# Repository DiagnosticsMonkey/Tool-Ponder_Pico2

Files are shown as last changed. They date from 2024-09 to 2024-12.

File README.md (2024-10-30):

# ReadMe

Ponder - Pico 2 is a varient of Ponder, designed to act as 6, electrically isolated, UART to USB bridges using the Pico 2.
Connect the board to your PC, and be served 6, driverless, COM-ports or ttyACM devices.

## Documentation

Documentation is captured in Markdown and is available in `/docs`, rendered [using docsify here](https://diagnosticsmonkey.github.io/Tool-Ponder_Pico2/#/).

## Design files

All of the design files are included in this repository.

### Hardware

Hardware design files are in [`/hardware`](https://github.com/DiagnosticsMonkey/Tool-Ponder_Pico2/tree/develop/hardware).

Generated outputs such as [Schematic](https://github.com/DiagnosticsMonkey/Tool-Ponder/blob/develop/hardware/outputs/Ponder-Pico2.pdf), [BoM](https://diagnosticsmonkey.github.io/Tool-Ponder_Pico2/#/design?id=bill-of-materials), and [Gerbers](https://github.com/DiagnosticsMonkey/Tool-Ponder_Pico2/tree/develop/hardware/outputs/fab) are all included.

### Software

Nominal software is available TBD.

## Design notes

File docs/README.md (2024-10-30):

# Ponder - Pico 2

> [!WARNING]This documentation is not yet complete

This board is primarily designed to act as a 6-way isolated USB-UART bridge using the Pico 2. This can be used to interface to multiple devices-under-test simultaneously.

Unlike FTDI devices, no additional drivers are required to be installed in order for the device to function as a UART to USB bridge; Support is baked in to modern operating system kernels using USB CDC ACM.

In short, it is a quick and convenient way to debug devices via UART. No need for multiple cables and isolators.

> [!NOTE]
> This board is a variant of [Ponder](https://diagnosticsmonkey.github.io/Tool-Ponder/#/)  
> It exists due to a pro-tracted lack of consumer supply for the RP2350B, yet abundant supply of Pico 2's. I want to get software sorted.

---

## Why Isolated?

There are a few reasons why it can be a good idea to electrically isolate your device under test from your test system, including:

1. Ground Loops -> Devices connected via UART may have different ground potentials. Without isolation, this could cause ground loops, which can lead to noise, signal integrity issues, or in severe cases, damage.
1. Damage to Equipment -> An isolated adapter prevents high-voltage from being passed to the USB port of the host computer.
   1. e.g. If you have a battery powered device and you're low-side switching, the product will float to the pack voltage when 'off'. This could damage any connected equipment due to the potential difference.
1. Noise Reduction -> Isolation reduces electrical noise, improving signal integrity and communication reliability.
1. Safety -> Protects the user, and equipment, when working with high-voltage or hazardous devices.
   1. N.B. electrical isolation should be verified by an electrical safety team before being used as a safety device.
1. Improved Debugging -> Issues with one device, shouldn't be able to impinge on the UART comms of another under test.

### Why not isolate the USB

By isolating the individual UARTs you're able to connect to different voltage domains simultaneously. This means that Ponder can be installed as part of a debug or test ecosystem for a full product comprising of multiple referencing domains.  
The downside is that even if you're communicating with several UARTs on the same board, each isolator requires its own voltage feed. 

---

## Naming

Ponder is named after [Ponder Stibbons](https://wiki.lspace.org/Ponder_Stibbons), Head of Inadvisably Applied Magic, and Reader in Invisible Writings.

Ponder Stibbons is from the [Discworld universe](https://wiki.lspace.org/Discworld_(world)), brought in to existence by [Sir Terry Pratchett](https://wiki.lspace.org/Biography).

---

## Attribution

- Pico footprint from ncarandini -> https://github.com/ncarandini/KiCad-RP-Pico
  - Modified to add Pico 2 TPs and adjust USB mount holes
- Raspberry Pi - Pico 2 model used is originally by DrakerDG -> https://www.tinkercad.com/things/4xIXctwrZsr-raspberry-pi-pico-2
  - Modified to add TPs https://www.tinkercad.com/things/fXc3pdA6Lbr-raspberry-pi-pico-2-w-tps-rough
  - Converted from `OBJ` to `WRL` using -> https://imagetostl.com/convert/file/obj/to/wrl

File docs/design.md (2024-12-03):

# Design

Design files are all available in `/hardware` of the Ponder_Pico2 repository.

## Appearance

The board is _reasonably_ self-explanatory for most _intended_ users and is presented as follows:

<!-- tabs:start -->

#### **Render**

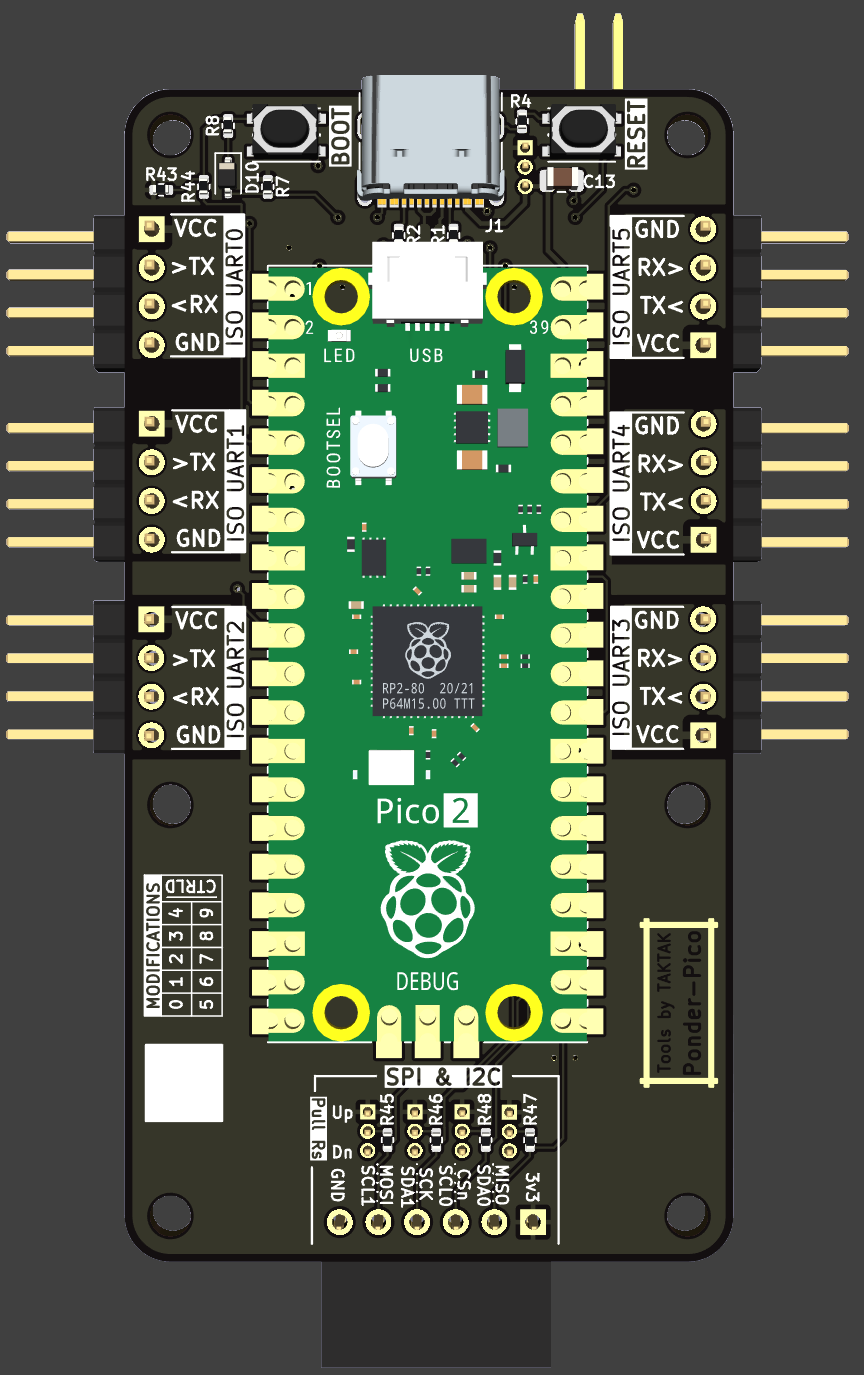
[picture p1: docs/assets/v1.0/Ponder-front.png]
Front of board :size=300
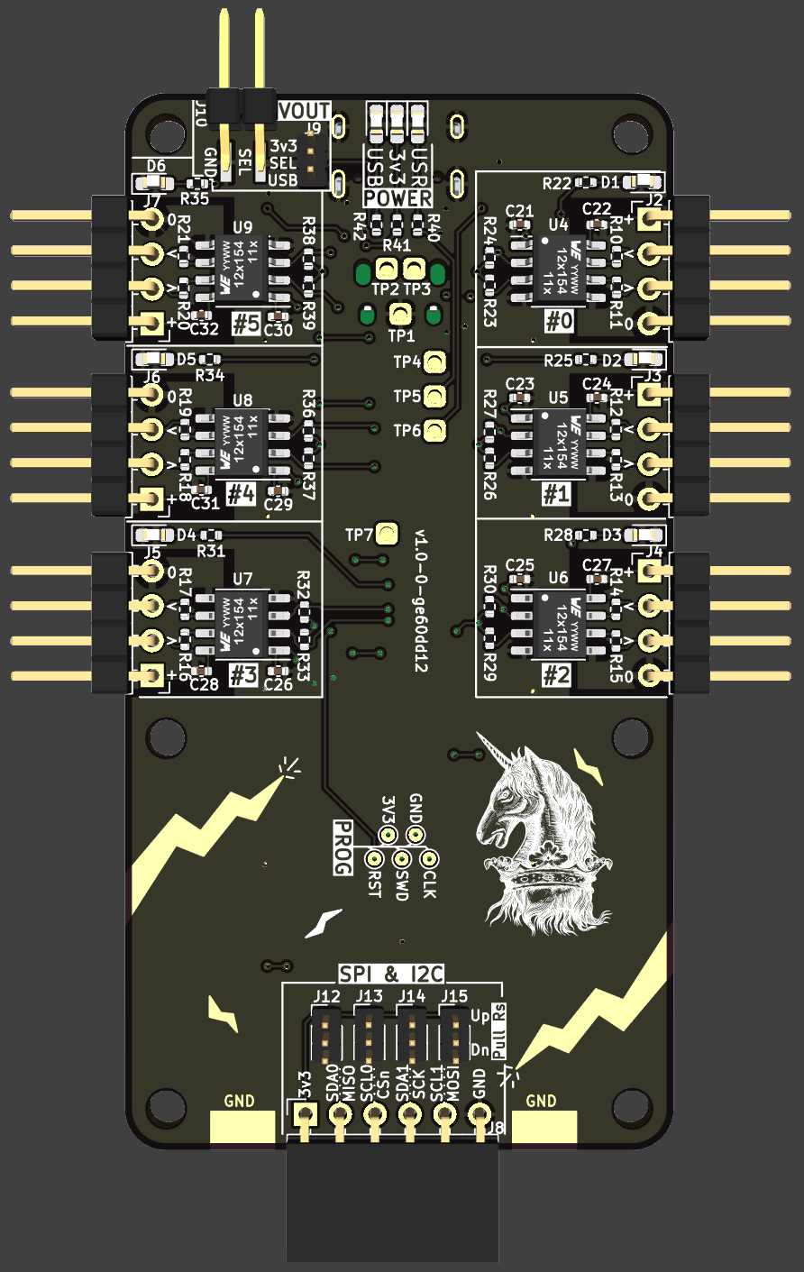
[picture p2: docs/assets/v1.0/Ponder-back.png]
Back of board :size=310
 

#### **Photo**

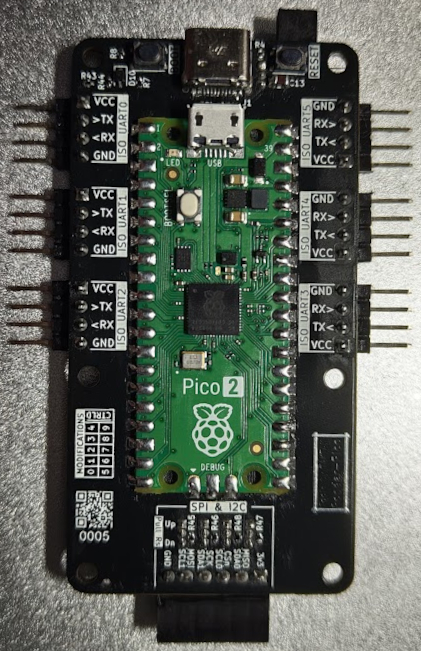
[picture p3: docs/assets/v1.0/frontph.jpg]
Front of board :size=300
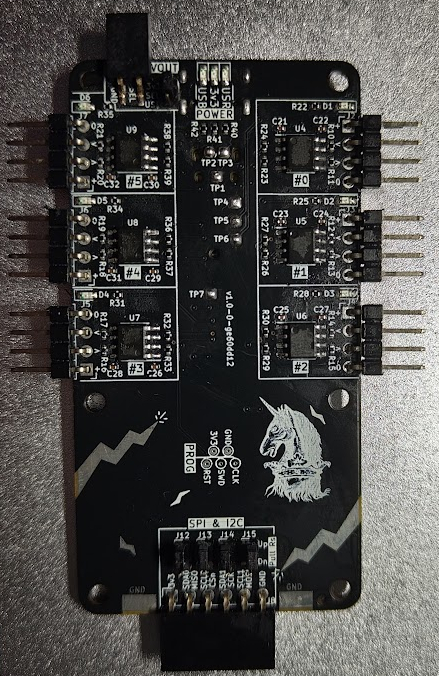
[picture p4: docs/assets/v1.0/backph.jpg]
Back of board :size=310
 

<!-- tabs:end -->

See [here for more detail of features and usage](/features)

---

## Bill of Materials

The below is an embedded copy of the interactive bill-of-materials, available in `/hardware/outputs/bom`.

[ibom](./assets/v1.0/ibom.html ':include :type=iframe width=100% height=800px')

---

## Schematic

Whilst the majority of the expanded headers are self explanatory, the following is embedded to provide a fuller picture of the board.

Available in `/hardware/outputs`.

```pdf
./assets/v1.0/Ponder-Pico2.pdf
```

---

## Miscellaneous

The following lists any miscellany.

### Board Revision

The board includes a version and revision marker which traces back to the applicable Git commit from which the bareboard was generated.

Revision

### Mod Strikes

On the rear of the board, there is a 'MODIFICATIONS' box for tracking board modifications via modification sheets, each assigned a number.
When a board is updated to a particular modification level, mark the corresponding box.

Mod strikes

Alternatively, if a board is used in a bespoke way, check the '/CTRLD' box to indicate it is not at a known, or controlled, build level.

>[!TIP]
>The `/CTRLD` box can be useful if you have multiple boards which you're tracking the status of, but you're experimenting heavily with one and are never intending on returning it to a defined build standard.

### Serialisation

Serialisation is provided next to the Mod Strike box in the form `ZZZZ`.

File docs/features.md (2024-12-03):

# Features

This page details the feature-set and pin-mapping at a high-level.

## Pinout

?>The following has been reproduced for ease of access, the schematic is the source of truth.

| Function | Ponder Pico2 | Ponder |
|:---:|:---:|:---:|
| UART0 TX | GPIO0 | GPIO0 |
| UART0 RX | GPIO1 | GPIO1 |
| UART0 LED | GPIO2 | GPIO2 |
| USR SW | GPIO3 | GPIO3 |
| UART1 TX | GPIO4 | GPIO20 |
| UART1 RX | GPIO5 | GPIO21 |
| UART1 LED | GPIO6 | GPIO8 |
| UART2 LED | GPIO7 | GPIO19 |
| UART2 TX | GPIO8 | GPIO22 |
| UART2 RX | GPIO9 | GPIO23 |
| UART3 LED | GPIO11 | GPIO30 |
| UART3 TX | GPIO12 | GPIO29 |
| UART3 RX | GPIO13 | GPIO28 |
| SPI**0** MISO/I2C0 SDA | GPIO16 | N/A |
| SPI**0** CSn/I2C0 SCL  | GPIO17 | N/A |
| SPI**0** SCK/I2C1 SDA  | GPIO18 | N/A |
| SPI**0** MOSI/I2C1 SCL | GPIO19 | N/A |
| UART4 RX | GPIO20 | GPIO32 |
| UART4 TX | GPIO21 | GPIO33 |
| UART4 LED | GPIO22 | GPIO34 |
| RP_PWR_LED | GPIO25 | GPIO4 |
| UART5 RX | GPIO26 | GPIO46 |
| UART5 TX | GPIO27 | GPIO47 |
| UART5 LED | GPIO28 | GPIO45 |

<details>
  <summary>For completeness -> SPI/I2C mapping for Ponder (Click to Expand)</summary>
Ponder Pico2 uses SPI0, Ponder uses SPI1.

| Function | Ponder Pico2 | Ponder |
|:---:|:---:|:---:|
| SPI**1** MISO/I2C0 SDA | N/A | GPIO24 |
| SPI**1** CSn/I2C0 SCL  | N/A | GPIO25 |
| SPI**1** SCK/I2C1 SDA  | N/A | GPIO26 |
| SPI**1** MOSI/I2C1 SCL | N/A | GPIO27 |

</details>

---

## Interfaces

The following sections will cover detail of various interfaces across the board.

>[!TIP]
>I _try_ to maintain the logic of not having `hot` supply pins as far as practicable.  
>This means that where possible, anything intended to provide a supply voltage will be in the form of a socket. Conversely, anything to be supplied a voltage will be presented as a header.  
>N.B. J10 is shown in renders as a header - It is a socket in the BoM. Its selection jumper, J9, is a 1.27 pitch for convenience.

---
### LEDS

There are three LEDs on the board which aren't for use with the ISO UARTS, these are:

1. USR - This is a user controllable LED, nominally used to indicate when the MCU has booted into user code
1. USB - This LED is tied to VBUS on the USB connector to indicate presence of power.
1. 3v3 - This is tied to the 3v3 line from the Pico to indicate that the LDO is functional.

### Buttons

#### BOOT

The BOOT button is used to put the MCU into USB bootloader mode in order to load *.UF2 files. Simply hold the button whilst powering on the board, then the board will present as a mass-storage device.

>[!TIP]
>Once booted, the button can act as a user input connected to `GPIO3`.

#### RESET

The reset button resets the device

### USB (J1)

The USB-C connector provides power to the board and is the primary mechanism for programming the board.  
During the boards intended use-case, the USB connector is also used for the data handling for the CDC ACM endpoints (i.e. your PC providing multiple COM ports for accessing each of the UARTs on-board).

---

### Isolated UARTs (J2, J3, J4, J5, J6, J7)

The isolated UARTs are provided by six 4 pin, 2.54 pitch, headers around the edge. The isolators connected to these headers `must` be fed with a voltage and ground reference by **each** device under test, otherwise the UART comms will not be passed to the MCU.

- Supply voltage on VCC for `UART`[`0` .. `5`] is 2.375 .. 5.5V  
   - The isolators are also providing level translation and will support logic from 2v0 to 5v5.

>[!NOTE]
>If you require 1v8 logic -> A drop-in replacement isolator is the [MAX12931](https://www.analog.com/media/en/technical-documentation/data-sheets/max12930-max12931.pdf).  
>This part is significantly higher cost, hence not the default.

---

### I2C / SPI / Breakout (J8, TPs)

The board includes some additional connection options for users to experiment with.

#### J8

J8 _nominally_ provides access to either `SPI0` _or_ `I2C0` & `IC21`. Additionally, the header provides 3v3 supply and GND connections.

J12 .. J15 provides optional pull-up / pull-down configuration for each pin by jumpering the desired end to the centre pin.

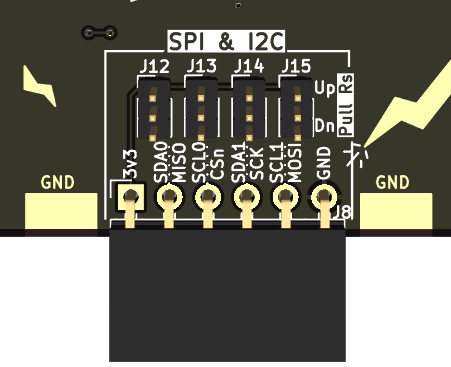
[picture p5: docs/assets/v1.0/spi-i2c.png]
SPI I2C :size=200


>[!TIP]
>These pins could be used for GPIO, for example for triggering wider aspects of a test system.

#### Programming

Test points are provided as an alternative to USB loading.

1. Programming test points are grouped near the MCU.
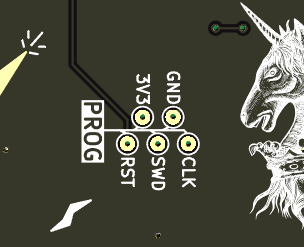
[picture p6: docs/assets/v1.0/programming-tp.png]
Prog :size=150
   1. 

### VOut (J10)

J10 is provided as a convenient power access for lower power devices or for monitoring supply voltages.  
The voltage on J10 can be selected, using J9. The options are 3v3 or USB.

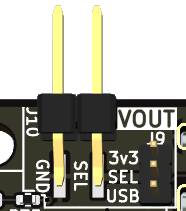
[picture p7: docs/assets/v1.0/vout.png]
VOUT


>[!WARNING]
>J10 _could_ be used to power the board, up-to 20V, when jumpered to USB, or a direct 3v3, bypassing the LDO (U1), if required.  
>If powering via the USB jumper option, note that USB LED, D9, is tied to this line and has 1kR in series.

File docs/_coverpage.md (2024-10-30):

:size=50%

#  Ponder <small>Pico 2 - 1.0</small>

>  Isolated Hexa UART-USB adapter from Diagnostics

- :see_no_evil:
- :hear_no_evil:
- :speak_no_evil:

[Purchase](/purchase)
[Getting Started](/README)

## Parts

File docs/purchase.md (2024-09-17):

# Purchase

To purchase Ponder for yourself, please contact me on `contact (at) taktak.co.uk` for details.

I'm currently working out where to make Ponder available, likely Tindie.

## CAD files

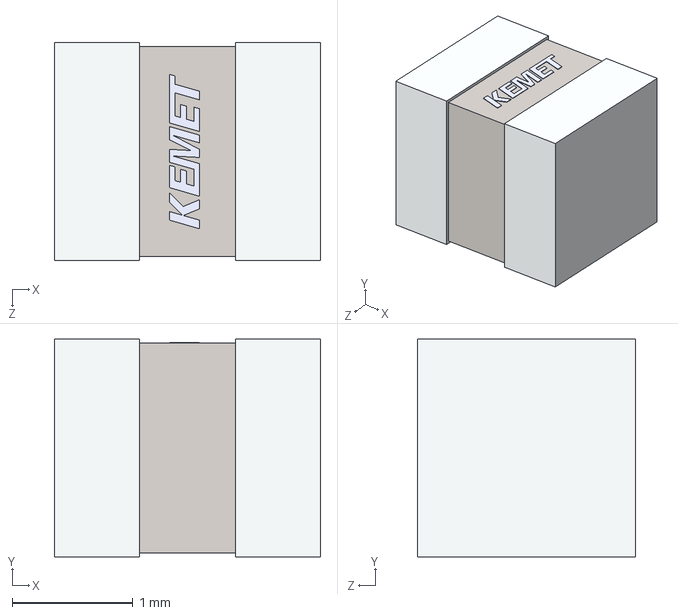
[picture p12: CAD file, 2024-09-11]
hardware/Parts/L0806.stp
2.20 x 1.80 x 1.80 mm

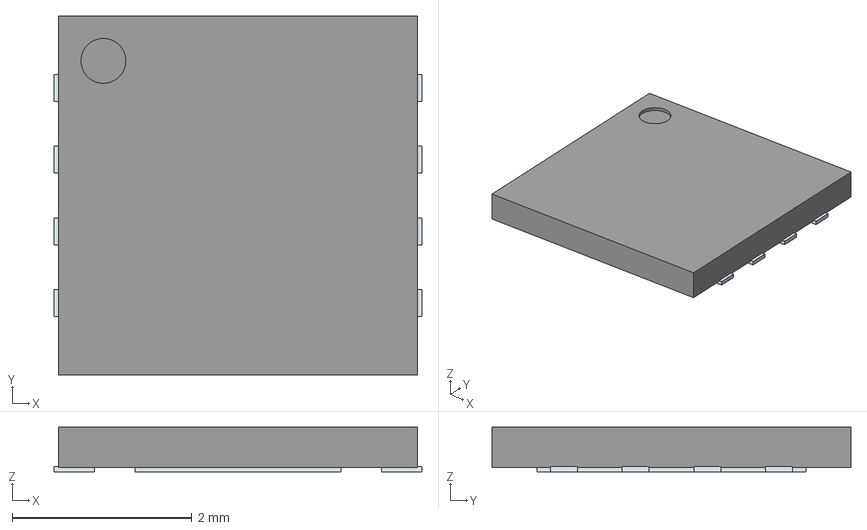
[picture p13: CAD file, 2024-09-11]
hardware/Parts/W25Q64JVXGIQ_TR.stp
4.10 x 4.00 x 0.5 mm
ThermalPin
PinsArrayLR

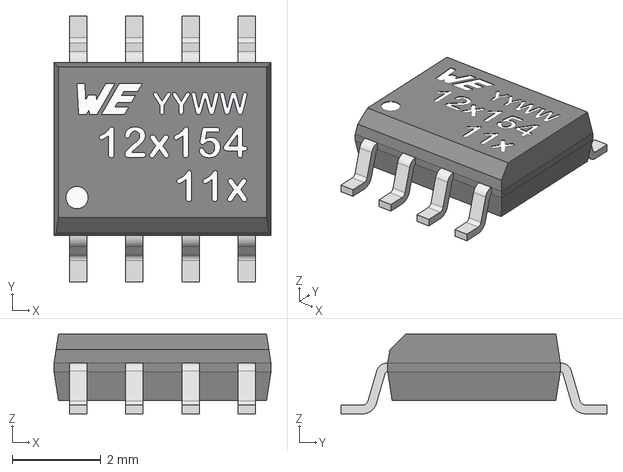
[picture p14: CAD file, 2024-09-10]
hardware/Parts/STP_CDIS_18012x15411x (rev1).stp
4.90 x 6.00 x 1.80 mm
Pins

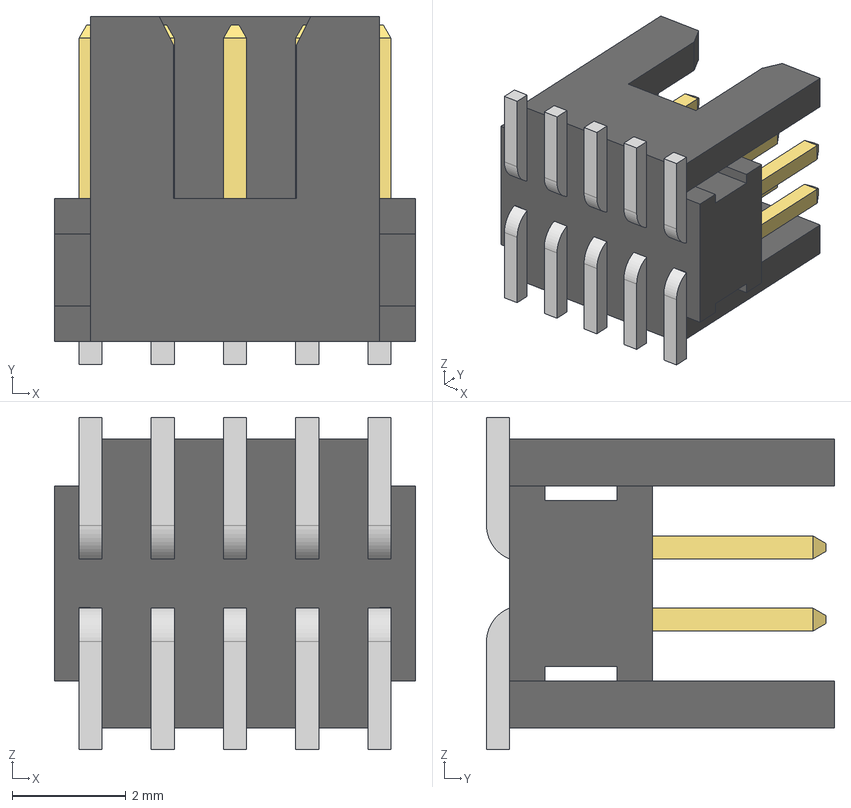
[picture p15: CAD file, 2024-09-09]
hardware/Parts/FTSH-105-01-L-DV-K.stp
6.35 x 6.12 x 5.84 mm
FTSH-105-01-L-DV-K_body
FTSH-105-01-L-DV-K_pins1
FTSH-105-01-L-DV-K_pins2

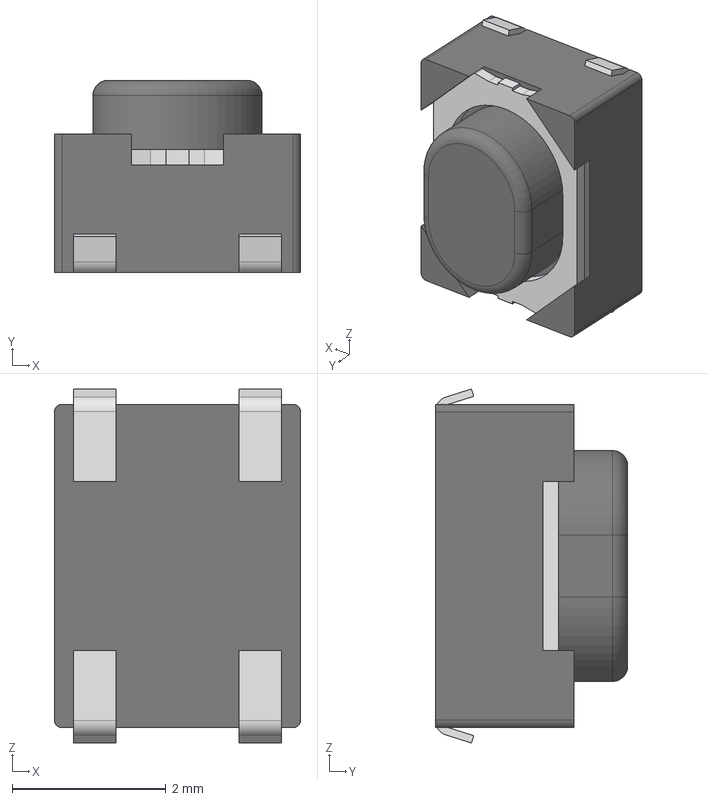
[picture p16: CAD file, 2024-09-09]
hardware/Parts/STP_4341x30258x6 (rev1).stp
3.20 x 2.50 x 4.60 mm
Frame
Cover
Stem
Terminal x 4

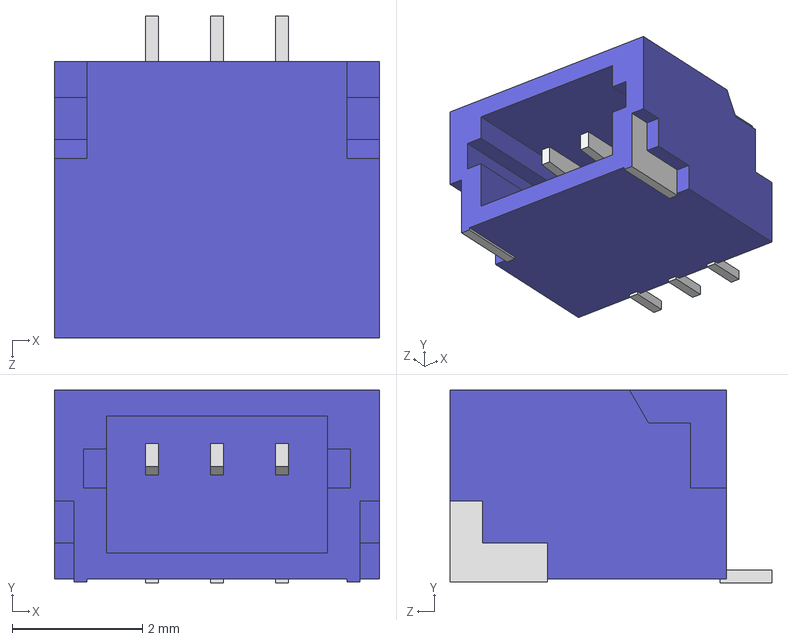
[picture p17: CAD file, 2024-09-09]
hardware/Parts/SM03B-SRSS-TB.step
5.00 x 2.96 x 4.95 mm

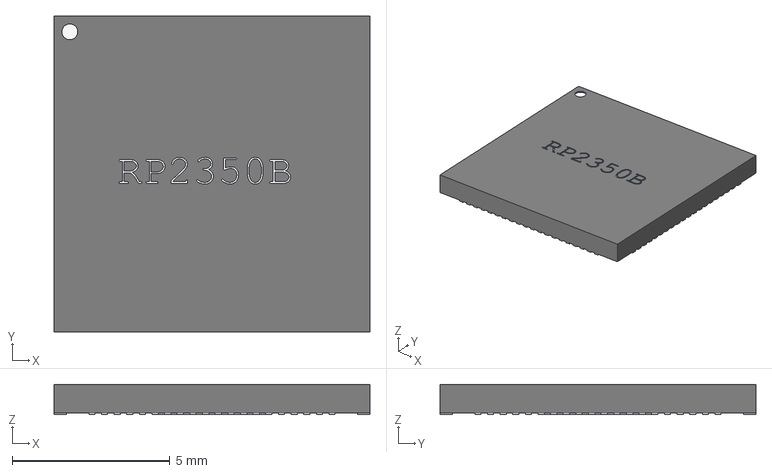
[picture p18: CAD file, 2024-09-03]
hardware/Parts/RP2350_QFN80.step
10.0 x 10.0 x 0.95 mm

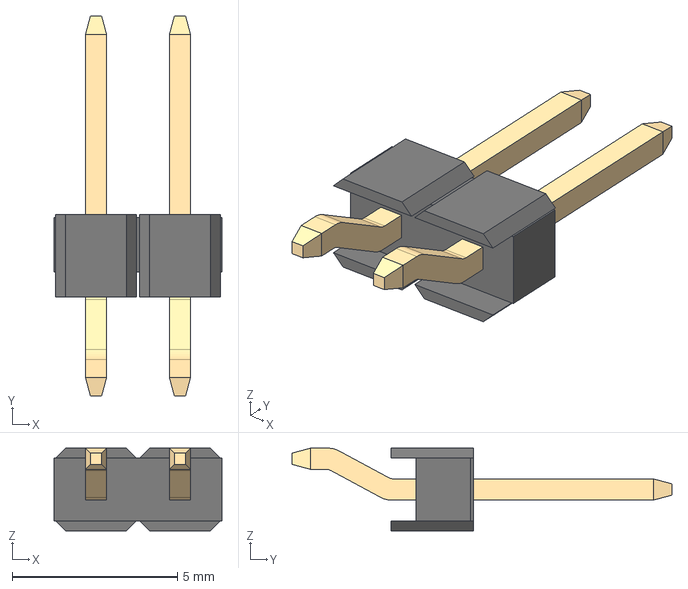
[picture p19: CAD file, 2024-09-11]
hardware/Parts/M20-8890245.stp
5.08 x 11.5 x 2.50 mm
M20-88902_MOULD
M20-889_CONTACT x 2

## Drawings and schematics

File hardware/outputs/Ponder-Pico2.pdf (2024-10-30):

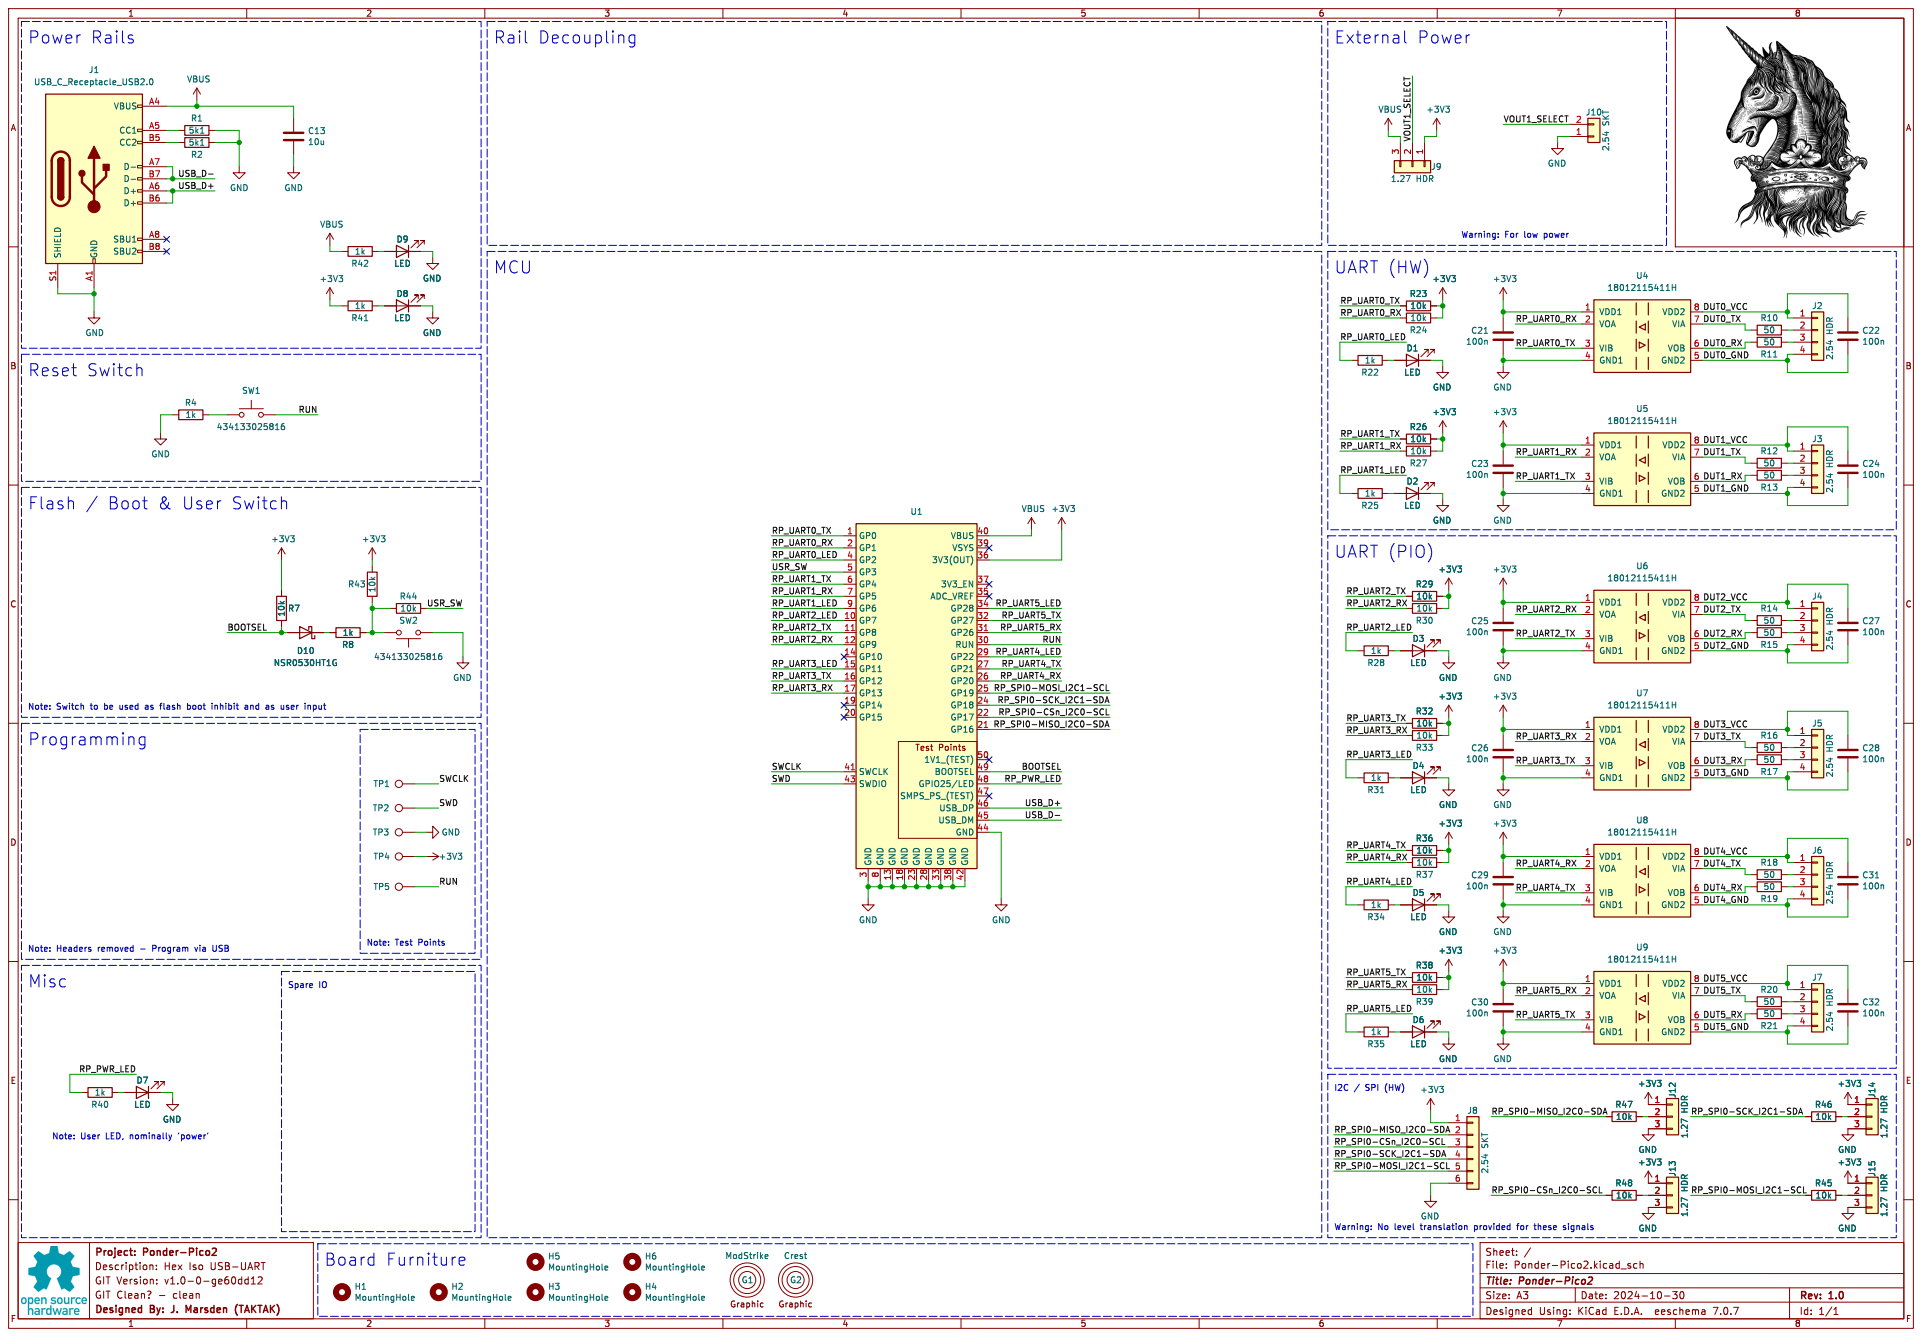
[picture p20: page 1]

BOOTSEL RP_SPI0-MISO_I2C0-SDA RP_SPI0-SCK_I2C1-SDA RUN

Flash / Boot & User Switch

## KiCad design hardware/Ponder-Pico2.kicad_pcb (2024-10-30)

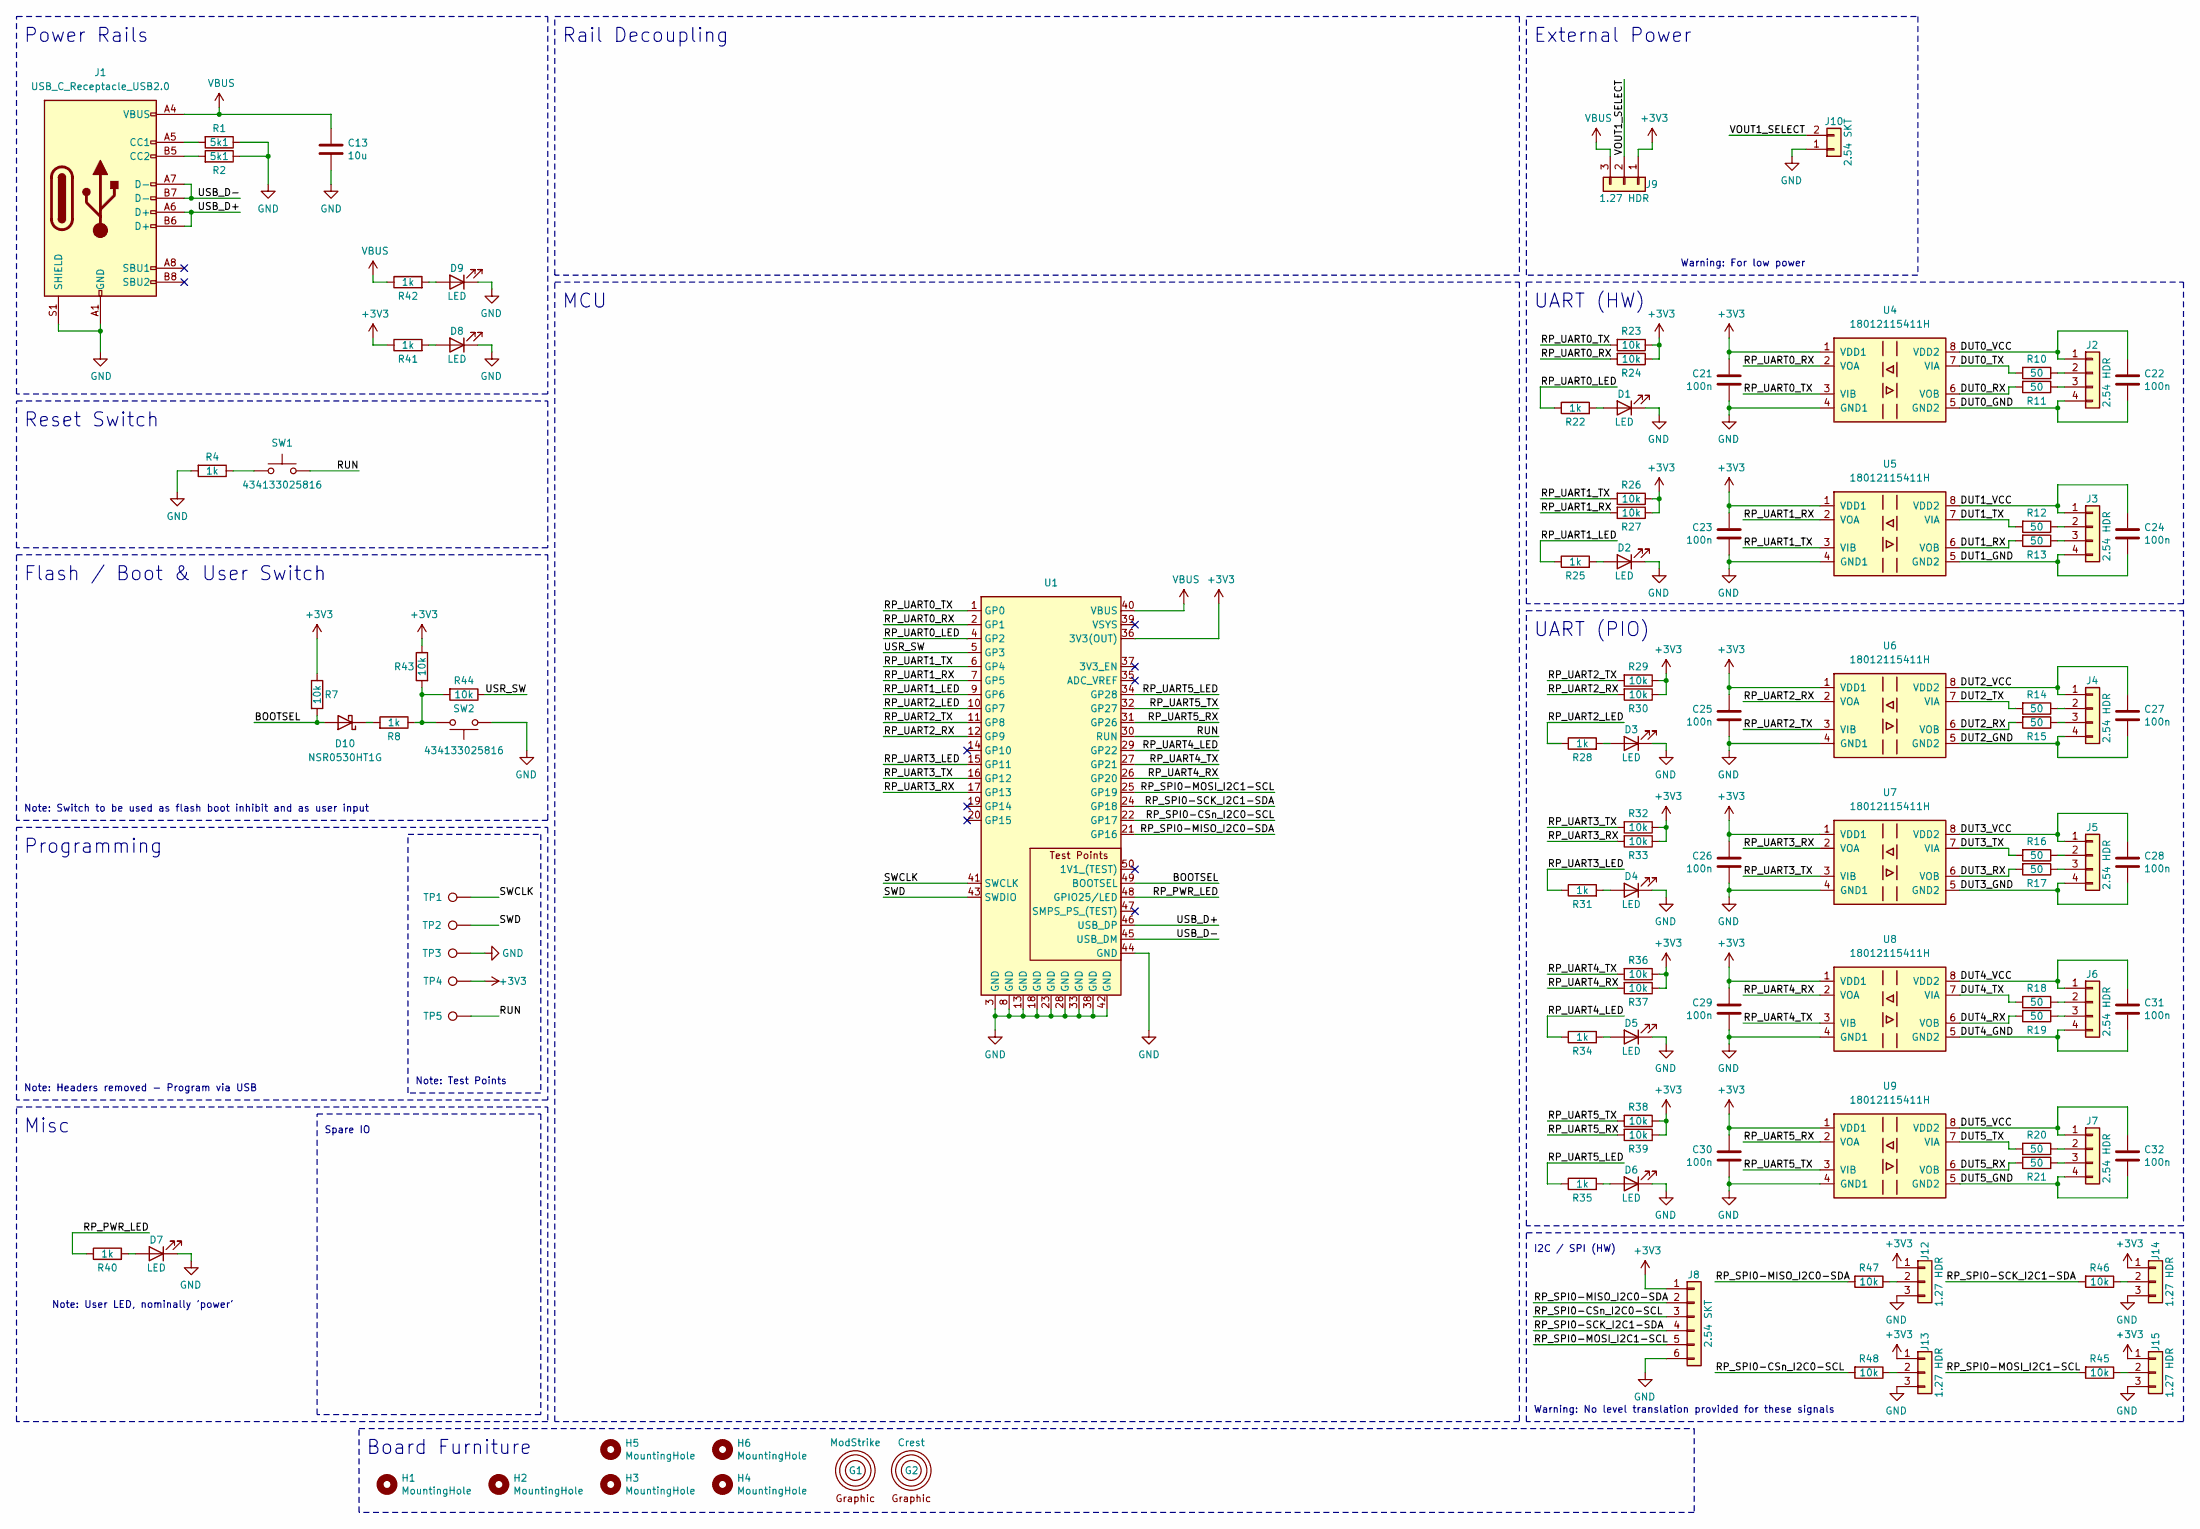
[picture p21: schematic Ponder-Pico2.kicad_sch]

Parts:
C13: 10u; C_0805_2012Metric
C21, C22, C23, C24, C25, C26, C27, C28, C29, C30, C31, C32: 100n; C_0402_1005Metric
D1, D2, D3, D4, D5, D6, D7, D8, D9: LED; LED_0603_1608Metric_Pad1.05x0.95mm_HandSolder
D10: NSR0530HT1G; D_SOD-323
G1: ModStrike
G2: Crest; Crest-10mm
H1, H2, H3, H4, H5, H6: MountingHole; MountingHole_2.7mm_M2.5
J1: USB_C_Receptacle_USB2.0; USB_C_Receptacle_GCT_USB4105-xx-A_16P_TopMnt_Horizontal
J2, J3, J4, J5, J6, J7: 2.54 HDR; PinHeader_1x04_P2.54mm_Horizontal
J8: 2.54 SKT; PinSocket_1x06_P2.54mm_Horizontal
J9, J12, J13, J14, J15: 1.27 HDR; PinHeader_1x03_P1.27mm_Vertical
J10: 2.54 SKT; M208890245
R1, R2: 5k1; R_0402_1005Metric
R4, R8, R22, R25, R28, R31, R34, R35, R40, R41, R42: 1k; R_0402_1005Metric
R7, R23, R24, R26, R27, R29, R30, R32, R33, R36, R37, R38, R39, R43, R44, R45, R46, R47, R48: 10k; R_0402_1005Metric
R10, R11, R12, R13, R14, R15, R16, R17, R18, R19, R20, R21: 50; R_0402_1005Metric
SW1, SW2: 434133025816; SW_Push_1P1T_NO_Vertical_Wuerth_434133025816
TP1, TP2, TP3, TP4, TP5: TestPoint; TestPoint_Pad_D1.0mm
U1: RaspberryPi-Pico-SMD-TP
U4, U5, U6, U7, U8, U9: 18012115411H; SOIC-8_3.9x4.9mm_P1.27mm

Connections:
+3V3: C21.1, C23.1, C25.1, C26.1, C29.1, C30.1, J8.1, J9.1, J12.1, J13.1, J14.1, J15.1, R7.1, R23.1, R24.1, R26.1, R27.1, R29.1, R30.1, R32.1, R33.1, R36.1, R37.1, R38.1, R39.1, R41.1, R43.1, TP4.1, U1.36 (3V3(OUT)), U4.1 (VDD1), U5.1 (VDD1), U6.1 (VDD1), U7.1 (VDD1), U8.1 (VDD1), U9.1 (VDD1)
/BOOTSEL: D10.2 (A), R7.2, U1.49 (BOOTSEL)
/DUT0_GND: C22.2, J2.4, U4.5 (GND2)
/DUT0_RX: R11.2, U4.6 (VOB)
/DUT0_TX: R10.2, U4.7 (VIA)
/DUT0_VCC: C22.1, J2.1, U4.8 (VDD2)
/DUT1_GND: C24.2, J3.4, U5.5 (GND2)
/DUT1_RX: R13.2, U5.6 (VOB)
/DUT1_TX: R12.2, U5.7 (VIA)
/DUT1_VCC: C24.1, J3.1, U5.8 (VDD2)
/DUT2_GND: C27.2, J4.4, U6.5 (GND2)
/DUT2_RX: R15.2, U6.6 (VOB)
/DUT2_TX: R14.2, U6.7 (VIA)
/DUT2_VCC: C27.1, J4.1, U6.8 (VDD2)
/DUT3_GND: C28.2, J5.4, U7.5 (GND2)
/DUT3_RX: R17.2, U7.6 (VOB)
/DUT3_TX: R16.2, U7.7 (VIA)
/DUT3_VCC: C28.1, J5.1, U7.8 (VDD2)
/DUT4_GND: C31.2, J6.4, U8.5 (GND2)
/DUT4_RX: R19.2, U8.6 (VOB)
/DUT4_TX: R18.2, U8.7 (VIA)
/DUT4_VCC: C31.1, J6.1, U8.8 (VDD2)
/DUT5_GND: C32.2, J7.4, U9.5 (GND2)
/DUT5_RX: R21.2, U9.6 (VOB)
/DUT5_TX: R20.2, U9.7 (VIA)
/DUT5_VCC: C32.1, J7.1, U9.8 (VDD2)
/RP_PWR_LED: R40.1, U1.48 (GPIO25/LED)
/RP_SPI0-CSn_I2C0-SCL: J8.3, R48.2, U1.22 (GP17)
/RP_SPI0-MISO_I2C0-SDA: J8.2, R47.2, U1.21 (GP16)
/RP_SPI0-MOSI_I2C1-SCL: J8.5, R45.2, U1.25 (GP19)
/RP_SPI0-SCK_I2C1-SDA: J8.4, R46.2, U1.24 (GP18)
/RP_UART0_LED: R22.1, U1.4 (GP2)
/RP_UART0_RX: R24.2, U1.2 (GP1), U4.2 (VOA)
/RP_UART0_TX: R23.2, U1.1 (GP0), U4.3 (VIB)
/RP_UART1_LED: R25.1, U1.9 (GP6); also elsewhere on the board
/RP_UART1_RX: R27.2, U1.7 (GP5), U5.2 (VOA)
/RP_UART1_TX: R26.2, U1.6 (GP4), U5.3 (VIB)
/RP_UART2_LED: R28.1, U1.10 (GP7)
/RP_UART2_RX: R30.2, U1.12 (GP9), U6.2 (VOA)
/RP_UART2_TX: R29.2, U1.11 (GP8), U6.3 (VIB)
/RP_UART3_LED: R31.1, U1.15 (GP11)
/RP_UART3_RX: R33.2, U1.17 (GP13), U7.2 (VOA)
/RP_UART3_TX: R32.2, U1.16 (GP12), U7.3 (VIB)
/RP_UART4_LED: R34.1, U1.29 (GP22)
/RP_UART4_RX: R37.2, U1.26 (GP20), U8.2 (VOA)
/RP_UART4_TX: R36.2, U1.27 (GP21), U8.3 (VIB)
/RP_UART5_LED: R35.1, U1.34 (GP28)
/RP_UART5_RX: R39.2, U1.31 (GP26), U9.2 (VOA)
/RP_UART5_TX: R38.2, U1.32 (GP27), U9.3 (VIB)
/RUN: SW1.2, TP5.1, U1.30 (RUN)
/SWCLK: TP1.1, U1.41 (SWCLK)
/SWD: TP2.1, U1.43 (SWDIO)
/USB_D+: J1.A6 (D+), J1.B6 (D+), U1.46 (USB_DP)
/USB_D-: J1.A7 (D-), J1.B7 (D-), U1.45 (USB_DM)
/USR_SW: R44.1, U1.5 (GP3)
/VOUT1_SELECT: J9.2, J10.2
GND: C13.2, C21.2, C23.2, C25.2, C26.2, C29.2, C30.2, D1.1 (K), D2.1 (K), D3.1 (K), D4.1 (K), D5.1 (K), D6.1 (K), D7.1 (K), D8.1 (K), D9.1 (K), J1.A1 (GND), J1.A12 (GND), J1.B1 (GND), J1.B12 (GND), J1.S1 (SHIELD), J8.6, J10.1, J12.3, J13.3, J14.3, J15.3, R1.1, R2.1, R4.2, SW2.2, TP3.1, U1.3 (GND), U1.8 (GND), U1.13 (GND), U1.18 (GND), U1.23 (GND), U1.28 (GND), U1.33 (GND), U1.38 (GND), U1.42 (GND), U1.44 (GND), U4.4 (GND1), U5.4 (GND1), U6.4 (GND1), U7.4 (GND1), U8.4 (GND1), U9.4 (GND1)
unnamed: D1.2 (A), R22.2
unnamed 58: D2.2 (A), R25.2; also elsewhere on the board
unnamed: D3.2 (A), R28.2
unnamed: D4.2 (A), R31.2
unnamed: D5.2 (A), R34.2
unnamed: D6.2 (A), R35.2
unnamed: D7.2 (A), R40.2
unnamed: D8.2 (A), R41.2
unnamed: D9.2 (A), R42.2
unnamed: D10.1 (K), R8.2
unnamed: J1.A5 (CC1), R1.2
unnamed: J1.B5 (CC2), R2.2
unnamed: J2.2, R10.1
unnamed: J2.3, R11.1
unnamed: J3.2, R12.1
unnamed: J3.3, R13.1
unnamed: J4.2, R14.1
unnamed: J4.3, R15.1
unnamed: J5.2, R16.1
unnamed: J5.3, R17.1
unnamed: J6.2, R18.1
unnamed: J6.3, R19.1
unnamed: J7.2, R20.1
unnamed: J7.3, R21.1
unnamed: J12.2, R47.1
unnamed: J13.2, R48.1
unnamed: J14.2, R46.1
unnamed: J15.2, R45.1
unnamed: R4.1, SW1.1
unnamed: R8.1, R43.2, R44.2, SW2.1
VBUS: C13.1, J1.A4 (VBUS), J1.A9 (VBUS), J1.B4 (VBUS), J1.B9 (VBUS), J9.3, R42.1, U1.40 (VBUS)

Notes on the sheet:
Warning: No level translation provided for these signals
UART (PIO)
Misc
Note: Switch to be used as flash boot inhibit and as user input
Flash / Boot & User Switch
Spare IO
Board Furniture
Rail Decoupling
Note: Test Points
Note: User LED, nominally 'power'
Note: Headers removed - Program via USB
External Power
UART (HW)
I2C / SPI (HW)
MCU
Warning: For low power
Reset Switch
Programming
Power Rails

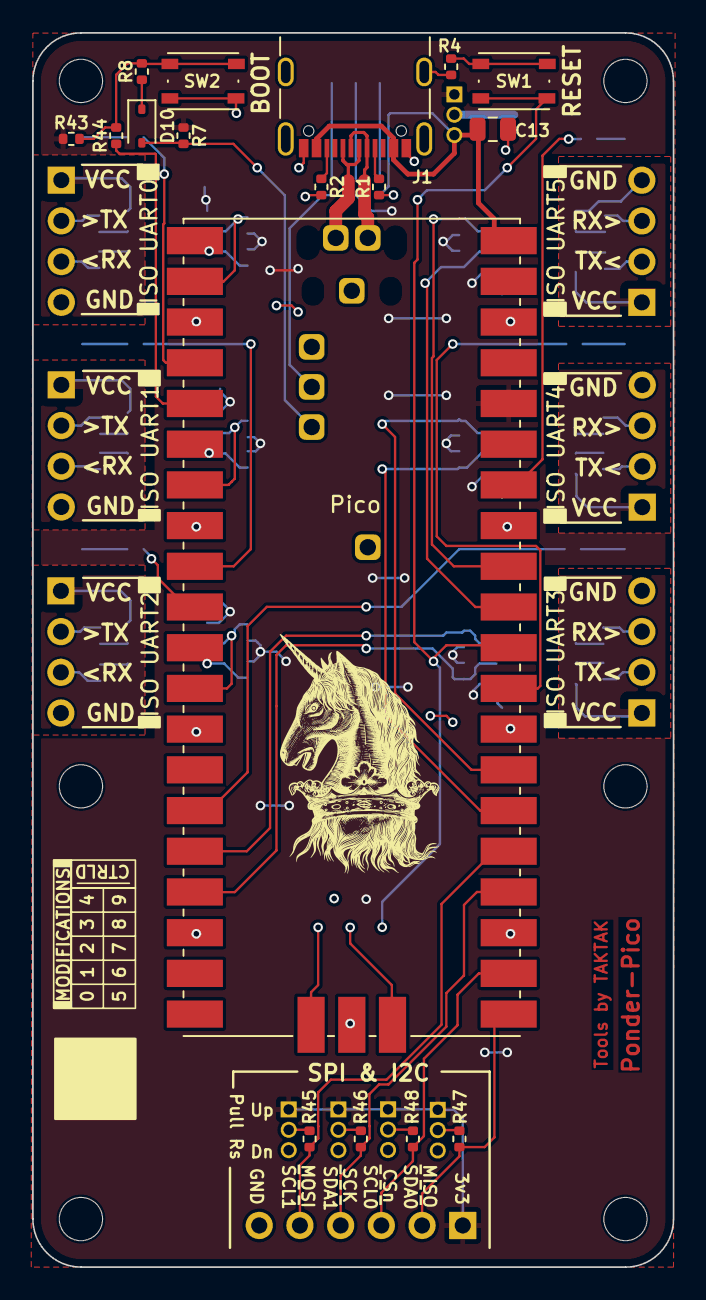
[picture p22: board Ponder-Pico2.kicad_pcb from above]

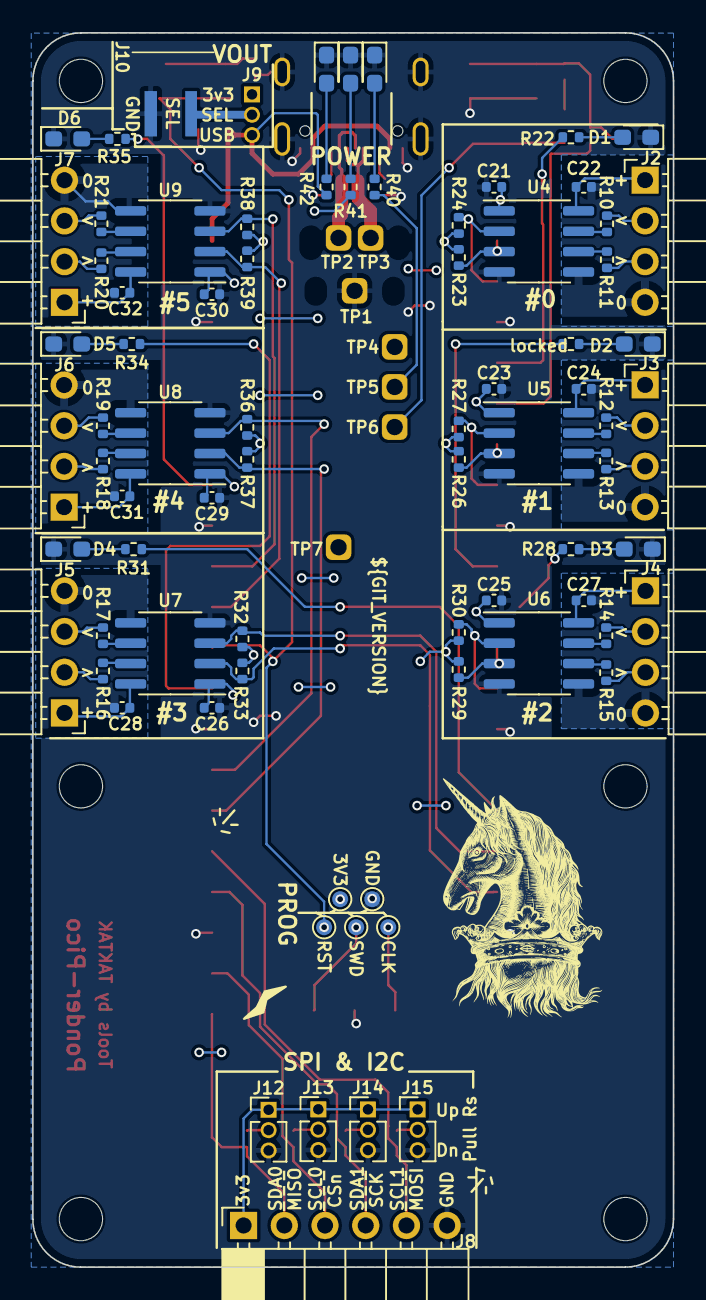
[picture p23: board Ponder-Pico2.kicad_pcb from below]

Board: 2 copper layers, 40.0 x 77.0 mm, 103 parts (79 on the bottom side), 88 nets.

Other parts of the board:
locked: 1k; R_0402_1005Metric

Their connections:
/RP_UART1_LED: locked.1; also elsewhere on the board
unnamed 58: locked.2; also elsewhere on the board

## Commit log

2024-09-03 Adding kicad template @7c4f6e5
    [template.kicad_pcb, template.kicad_sch]
2024-09-03 Updating template for project
    [Ponder.kicad_pcb, Ponder.kicad_sch]
2024-09-03 Adding baseline MCU and supportive blocks
    [Ponder.kicad_sch, RP2350_QFN80.step]
2024-09-09 Adding programming headers, some testpoints, and minimal MCU fanout with power
    [Ponder.kicad_pcb, Ponder.kicad_sch]
2024-09-09 Checking border update script
    [Ponder.kicad_pcb, Ponder.kicad_sch]
2024-09-09 Adding 3d models of parts
    [FTSH-105-01-L-DV-K.stp, Ponder.kicad_pcb, SM03B-SRSS-TB.step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]
2024-09-09 Fixing board outline, aligning USB connector to board edge, clearing some early DRC errors
    [Ponder.kicad_pcb]
2024-09-10 Adding modstrike box
    [Ponder.kicad_pcb, Ponder.kicad_sch]
2024-09-10 Adding ISOs and 4P headers
    [Ponder.kicad_pcb, Ponder.kicad_sch, STP_CDIS_18012x15411x (rev1).stp]
2024-09-10 Changing step file used for ISO
    [Ponder.kicad_pcb]
2024-09-10 Adding pull-ups and LEDs for UARTs. Added nominal I2C and SPI connector along with startes of some selectable off-board low power headers
    [Ponder.kicad_pcb, Ponder.kicad_sch]
2024-09-10 Updating boarder props via script
    [Ponder.kicad_pcb, Ponder.kicad_sch]
2024-09-10 Adding LEDs for power status
    [Ponder.kicad_pcb, Ponder.kicad_sch]
2024-09-10 Tittivating connector legends
    [Ponder.kicad_pcb]
2024-09-10 Minor tweaks an bit of layout
    [Ponder.kicad_pcb]
2024-09-11 Swapping flash in sch for part which isn't the size of a small exoplanet
    [Ponder.kicad_sch, W25Q64JVXGIQ_TR.stp]
2024-09-11 First pass layout
    [L0806.stp, M20-8890245.stp, Ponder.kicad_pcb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]
2024-09-11 Silk tittivating
    [Ponder.kicad_pcb, Ponder.kicad_sch]
2024-09-11 C15 & 16 RefDes had escaped the box when changing footprint
    [Ponder.kicad_pcb]
2024-09-11 Re-routing temporarily shelved items. Fixing DRC
    [Ponder.kicad_pcb]
2024-09-12 Border update and exclusions
    [Ponder.kicad_pcb, Ponder.kicad_sch]
2024-09-12 Aligning noconnects
    [Ponder.kicad_sch]
2024-09-16 Adding version fields and silk elements
    [Ponder.kicad_pcb]
2024-09-16 Updated borders, generated outputs for review. N.B. this applies and must be manually checked each time: https://gitlab.com/kicad/code/kicad/-/issues/14360
    [Ponder-B_Cu.gbr, Ponder-B_Mask.gbr, Ponder-B_Paste.gbr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]
2024-09-17 Unifying vias to single drill. Adding some plane connections
    [Ponder.kicad_pcb]
2024-09-17 Updating borders and version info for release. Generated output files
    [Ponder-B_Cu.gbr, Ponder-B_Mask.gbr, Ponder-B_Paste.gbr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]
2024-09-30 Typo on schematic filename
2024-10-30 Adding start of Pico 2 variant for Ponder
    [Ponder-B_Cu.gbr, Ponder-B_Mask.gbr, Ponder-B_Silkscreen.gbr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]
2024-10-30 Modifying Pico footprint for USB holes to match DS
    [Ponder-Pico2-B_Cu.gbr, Ponder-Pico2-B_Mask.gbr, Ponder-Pico2-B_Paste.gbr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]
2024-10-30 Template update
    [Ponder-Pico2.kicad_pcb, Ponder-Pico2.kicad_sch]
2024-10-30 Generated outputs for 1.0, including layout bug on silk property
    [Ponder-Pico2-B_Cu.gbr, Ponder-Pico2-B_Mask.gbr, Ponder-Pico2-B_Paste.gbr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]
2024-10-30 Linking correct model to footprint
    [Ponder-Pico2.kicad_pcb]
2024-10-30 Quick cut of docs for Pico 2 variant
2024-10-30 Incorrectly cross-referencing to Ponder. Also changed silk and mask colour
    [Ponder-Pico2.kicad_pcb]
2024-10-30 Fix board lighting issue in images and swap for black mask

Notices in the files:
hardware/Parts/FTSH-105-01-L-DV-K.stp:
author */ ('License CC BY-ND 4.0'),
